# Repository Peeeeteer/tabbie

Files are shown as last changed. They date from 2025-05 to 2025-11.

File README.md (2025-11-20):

<div align="center">

# 🤖 Tabbie  
Ever wanted a **to-do app with a Cute Face**? One that lives on your desk?

**That's Tabbie.**

[🛠️ Get started](https://tabbie.me) · [📺 Follow the build](https://www.youtube.com/@LloydDecember1) · [👥 Join the community](https://www.reddit.com/r/deskbuddy/) · [📘 Hardware Starer Guide](https://tabbie.me/hardware-guide)

</div>

---

## 🧠 What is Tabbie?

**Tabbie is a DIY desk robot that helps you work, focus, and learn.**  
It's like a to-do app — but physical, local, and full of personality.

Tabbie lives on your desk, connects to your computer, and helps with small daily things like:
- ✅ Managing your to-do list
- ⏲️ Running Pomodoro timers
- 🔔 Setting reminders (like "drink water every 30 mins")
- 😋 Making faces, moving around, and being silly
- 🗣️ Talking to you (coming soon!)

**Think:** a mini Twitch streamer sitting on your desk, cheering you on — but also keeping you on track.

https://github.com/user-attachments/assets/2cbf9e57-a491-4764-b69d-660fd9c50714

## ✨ Made to Be Built

Tabbie is open-source and totally customizable.  
You can build it yourself with 3D-printed parts and off-the-shelf components — [or just buy a Kit.](https://www.tabbie.me/buy)

Powered by:
- An ESP32 microcontroller
- A local React dashboard that talks to the robot
- 3D-printed body with custom designs and colors

If you're new to electronics:  
I also put together a [simple hardware starter guide](https://tabbie.me/hardware-guide) that explains the basics behind Tabbie

---

## 🚀 Get Started(STIL WIP, BUT FULL INSTRUCTIONS COMING NOVEMBER 10)

Start with the step-by-step guide (WITH A **15 MINUTE VIDEO TUTORIAL**):
- 👉 See: [`docs/get_started.md`](docs/get_started.md)

That guide covers:
- Installing the Dashboard
- Flashing the ESP32 firmware
- Connecting the dashboard to your Tabbie
- First run checklist

<!-- 
**📚 Dont know anything about electronics?**  
Go here and get started → [`docs/learning/README.md`](docs/learning/README.md) — This is my mini-roadmap that I did... try learning the same _(not sure if its the best and Im kinda stupid but yea)_
-->
---

## 🗂️ Project Structure

```txt
tabbie/
├── app/                      # React control panel
│
├── firmware/                 # Code that runs on devices
│
├── hardware/                 # Physical build assets (STL files)
│
├── docs/                     # Docs (kept simple for now)
│   ├── get_started.md
│
├── CONTRIBUTING.md
└── README.md
```

---

Want to understand Tabbie’s internals or eventually modify the hardware? [There’s a beginner-friendly hardware guide here](https://tabbie.me/hardware-guide)

## 🤝 Contributing

Contributions are welcome, but lets talk first!

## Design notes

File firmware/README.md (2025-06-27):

I purchased this small one (These are affiliate links. I may earn a commission at no extra cost to you)

EU: 22 EUR
https://amzn.to/4jXdnxq

## 1. ESP32 working test

For the setup I again did this:
https://gyazo.com/37ea603742f484d6cf2d05bb1ba84736

Simple check for if the onboard led is blinking aka that everything is working fine.

## 2. ESP32 + GME12864-11

We can get started with the ESP32 + GME12864-11 LED screen, basicly the one I got here https://amzn.to/4jXdnxq
Idea is to just show a face
Maybe then show a animation & then we could test the other screens I think?

The code is as it is under the ## 2. ESP32 + GME12864-11

And now you just need to connect to the esp32:

VCC → 3.3V 
GND → GND
SCL → GPIO 22 (default I2C clock pin)
SDA → GPIO 21 (default I2C data pin)

Now are display a simple static thing on the screen:
Image of the thing on my phone, will link later.

I quized myself as usual to understand the code but yea.

# 3. ESP32 + GME12864-11 + lopaka.app

Now using:
https://lopaka.app/gallery#trending

We will create a looping animation of the character blinking and the looking to the side.

Yea, 
just go to the url and make your 4 face screens & or just copy the ones I have and see the code.

### Just thinking

Seems like after more consideration, I will be switching to a Raspberry Pi Zero 2 W

the esp32 is not a good usecase in our situation, as esp32 is more of a outdoor low battery consumtion thing rather than mine on pc, gets to be charger all the time thing.

So basicly esp32 is just for the exact small electronic things, like quick weather sensor that sends data to your server and such

Simple "do one thing well" devices

Not sure, that might be version 2 and for now ill just make aversion 1 that does all the calculation etc.. on the pc/localy and just sends what to do the esp32.

Like,
User just started pomodoro (focus face or something?)

Exported chat to D:\tabbie 

# 4. ESP32 + GME12864-11 + lopaka.app + send faces

The goal now is to see whether for battery safety and not using rasberypie to use esp32 as just sort of middle maschine as I dont want to use rasberypie and some weird large batteries to Tabbie.

All the calculation and things will happen on the local pc/laptop, as in if we start a pomodoro, we send the animations for that to the esp32 and wipe the rest

So lets just actually try that, a simple "waiting animation" that is always on the esp32 and once we click on "Start pomodoro" in the dashboard, we show the "focus face"

Also,
We need resue the .env file and the load_env.py file from the previous esp32 basics.

So yes,
We are able to stream images / bits over wifi to show on the face but actually maybe not required.

anyway,
added the same thing now where users are able ot control over wifi and also in the frontend dashboard add their wifi login and such.

A real pain in the ass to make it as easy as possible for someone to connect their tabbie and ran into a bunch of bugs when setting the thing up with a new esp32 which is good to learn now 
not once people start using it.

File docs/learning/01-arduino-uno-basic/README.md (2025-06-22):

I purchased these things (These are affiliate links. I may earn a commission at no extra cost to you)

EU: 20 EUR
https://amzn.to/4jXdnxq
https://amzn.to/3GIhij3

US: $25
https://amzn.to/42Nb3lt
https://amzn.to/3RBpxQt

And the goal was to:
Show a screen and a mic and have it read and show that thing it read on a web page?

## Things I did.

## 1.1 Lights
I installed vs code ardunio extensions

1.2.
Watched this tutorial:
https://www.youtube.com/watch?v=I0ZIrzoI61g

1.3.
Ran into some problems running Arduino with VSCODE, watching this
https://www.youtube.com/watch?v=gQ2lsSuXvVU

Ended up installing platformio.ini which seems to be the main one anyone uses for boards like these?

If your on a Mac and you dont see the extension, you will need to pip install the platformio and then manually do the project init and such, without the extension gui (But if you on VS code it should be fine)

NOW Arudino does the ligth thing:

The code is inside ../src/main.cpp 
Dont forget to pio lib install "Servo" (Komment and unkomment code for each part)

https://github.com/user-attachments/assets/9d56f506-6bd0-425b-b68e-76e2e1bc5504

On to next thing.

## 2.1 Potentiometer

With a Potentiometer, you can now turn the ligth led up and down. Same code in the main.cpp file 

https://github.com/user-attachments/assets/5a38a1b8-3e5c-4d68-8e2c-4ae03be7157e

2.2 Potentiometer

Exact Same code but you can also use it to turn a Fan Motor... which is cool.

https://github.com/user-attachments/assets/15904203-2893-4038-a614-c387fcf38571

## 3.0 Servos/Step Motors 

Move servo with ptanetiomoter.

## 3.1 Same thing, but now with tabbie head (The head will definetly look better in the future)

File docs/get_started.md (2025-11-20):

# Getting Started with Tabbie

> STILL WORKING ON THIS - COME BACK ON NOVEMBER 10, 2025 (_but you can alrdy grab the parts on amazon now if you want save time)_

A mini Twitch streamer on your desk, cheering you on, but also keeping you focused. Lets make one

---

## What You'll Need

### The Parts (~$18 USD / ~€16 EUR total)
- **ESP32** (the robot's brain)
- **1.3" OLED Screen** (the face)
- **3D Printed Parts** (the body)
- **Jumper Wires** (connecting everything)

I recommend buying the parts on **Amazon or Aliexpress**  
**Amazon** is safe choice and fast shipping, but will be more expensive  
**Aliexpress** is cheaper, but things sometimes arrive broken and shipping takes long  

**Amazon EU:**
- [ESP32 USB-C](https://amzn.to/4mDWJ6Z) (~14 EUR) 
- [OLED Screen - Pack of 3](https://amzn.to/4nxXHCO) (~18.99 EUR)
- [JumperWires -  Full pack](https://amzn.to/4mOGZ0I) (~6.40 EUR)
- [PLA Filament for 3D printing](https://amzn.to/46QfHkC) (~14 EUR)

**Amazon US**
- [ESP32 USB-C](https://amzn.to/4mGymW4) (~13.99 USD)
- [OLED Screen](https://amzn.to/4nGTbSQ) (~17.99 USD)
- [JumperWires -  Full pack](https://amzn.to/4nFxh2a) (~6.80 USD)
- [PLA Filament for 3D printing](https://amzn.to/46yAlqL) (~13.99 USD)

**Aliexpress Worldwide:**
- [ESP32 USB-C](https://s.click.aliexpress.com/e/_c3wydxSb) (~6.99 USD / 5.20 EUR a piece)
- [1.3 INCH OLED Screen white](https://s.click.aliexpress.com/e/_c30oI6Nd) (~5.35 USD / 4.50 EUR)
- [JumperWires](https://s.click.aliexpress.com/e/_c3SbwD0R) (~3.30 USD / 2.59 EUR)
- [PLA Filament for 3D printing](https://s.click.aliexpress.com/e/_c3O5ECAR) (~15.50 USD / 13.50 EUR)

*These are affiliate links - I get 3% at no extra cost to you!*

## **Don't want to deal with parts & printing?** [Pre-order a complete kit here](https://www.tabbie.me/buy/kit)

<div align="center">

### **START. How to Build Tabbie**
**The video below covers everything for both Windows and Mac users.**

</div>

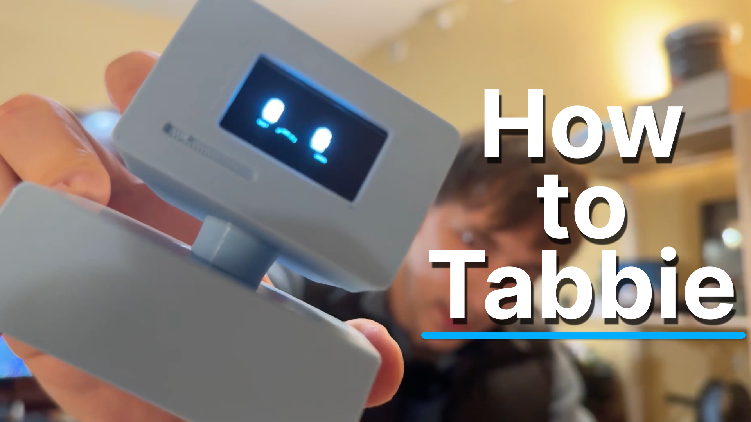
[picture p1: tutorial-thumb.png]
Watch the video (https://youtu.be/OyjsMKxYkQ0)


---

### STEP 1: Install & Download 

>Install:
1. **Node.js** (v18 or newer) - [Download](https://nodejs.org/) - Runs the dashboard web app
2. **Visual Studio Code** - [Download](https://code.visualstudio.com/) - Editor to view and modify code
3. **PlatformIO** (for programming the ESP32) - [Download](https://platformio.org/) - Uploads firmware to ESP32
4. **Git** - [Download Git](https://git-scm.com/)  To download via command line using `git clone`  

>Download:

**Option A: Using Git**   

```bash
git clone https://github.com/Peeeeteer/tabbie.git
cd tabbie
```

**Option B: Download as ZIP**

- Go to https://github.com/Peeeeteer/tabbie
- Click the green “Code” button
- Select “Download ZIP”
- Extract it somewhere easy to find

*[Image here showing how to download ZIP]*

### STEP 2: Print the Body/Enclosure   

1. Use the STL files from the `/hardware` folder & print
      - `hardware/GCODE.bgcode`
      - `hardware/STL/antenna.stl`
      - `hardware/STL/antenna2.stl`
      - `hardware/STL/bottom_case.stl`
      - `hardware/STL/case.stl`
      - `hardware/STL/neck.stl`
      - `hardware/STL/panel.stl`
      - `hardware/STL/top_case.stl`

**Tip:** Turn on supports for `neck.stl` and `top_case.stl` 

### STEP 3: Install ESP32 Drivers

Your ESP32 (brains) needs special drivers to talk to your computer.

**Windows Users:**
1. Download drivers from [Silicon Labs](https://www.silabs.com/software-and-tools/usb-to-uart-bridge-vcp-drivers?tab=downloads)
2. Install them
3. Plug in your ESP32 with a USB cable
4. Open Device Manager - you should see "Silicon Labs CP210x USB to UART Bridge"

**Mac/Linux Users:**
- Usually works automatically when you plug it in
- If it doesn't work, type this in Terminal: `brew install --cask silicon-labs-vcp-driver`

---

### STEP 4: Connect the Parts

**Wiring Guide:**
1. Partly Asemble Enclosure (as per video)
2. Connect the OLED screen to ESP32:
   - SDA wire → GPIO 21 (D21)
   - SCK/SCL wire → GPIO 22 (D22)
   - VDD → 3.3V 
   - GND → GND (Ground)

Keep it partly assembled (we need to upload code and make sure everything works first)

GG. done

---

### STEP 5: Program Your ESP32

1. **Navigate to the firmware folder:**

```bash
cd firmware
```

2. **Set up your WiFi credentials:**
   - Find the file `src/.env.example`
   - Make a copy of it in the same location
   - Rename the copy to `.env` (remove "example")
   - Open `.env` in Visual Studio Code or any text editor
   - Add your WiFi details: 

```
WIFI_SSID=your_wifi_name_here
WIFI_PASSWORD=your_wifi_password_here
```

**Tip:** Make sure its the same Wifi that your computer is connected to 

3. **Upload the code to your ESP32:**

```bash

# Go to the dashboard folder
cd firmware

pio run --target upload
```

**Tip:** If upload fails, hold down the BOOT button on your ESP32 while uploading
and make sure that your are in still in the `firmware` directory when uploading 

4. Finish assembling Tabbie.

Put the screen in the front -> front in the head

---

### STEP 6: Set Up the React Dashboard

Open your terminal/command and run:

```bash
# Go to the dashboard folder
cd app

# Install everything it needs
npm install

# Start it up
npm run dev
```

The dashboard will open at `http://localhost:8080` in your web browser.

---

### STEP 7: Connect Everything Together

1. **Open the dashboard** at `http://localhost:8080` in your browser
2. Follow the onboarding steps
3. **Watch the magic!** Tabbie should start showing its idle animation

**Tip:** Sometimes things just break, so disconnect tabbie for a few seconds and plug back in if wifi is not connecting properly. 

---

### Let's Use Tabbie!

**Create Tasks**
- Go to the Tasks tab
- Add things you need to do
- Start pomodors for tasks
- Tick it of when finished

Tabbie will show focus, happy,relax and bored animations a long the way to keep you focused.

**Important:**  
All your tasks/notes etc... are only saved on your computer, no one can access them.

---

## Troubleshooting

### ESP32 Won't Connect
- Double-check your WiFi name and password in the `.env` file and press "save"
- Make sure your ESP32 and computer are on the same WiFi network

### Dashboard Won't Start
- Make sure you ran `npm install` in the `dashboard` folder
- Check that you have Node.js v18 or newer (type `node --version` to check)
- Try running `npm run dev` again from the `dashboard` folder

### Can't Upload Code to ESP32
- Install the CP2102 drivers (see Step 3)
- Hold the BOOT button on ESP32 while uploading
- Check your USB cable (some cables only charge, they don't transfer data)

**Need more help?** Join the community:
- [Discord](https://discord.gg/7er2Ysjc) - [Reddit](https://www.reddit.com/r/deskbuddy/) - [YouTube](https://www.youtube.com/@LloydDecember1) - [GitHub](https://github.com/Peeeeteer/tabbie) - [X](https://x.com/llo7d)

---

## That's It!

If this helped you, consider giving the project a star on [GitHub](https://github.com/Peeeeteer/tabbie)!

Happy building!

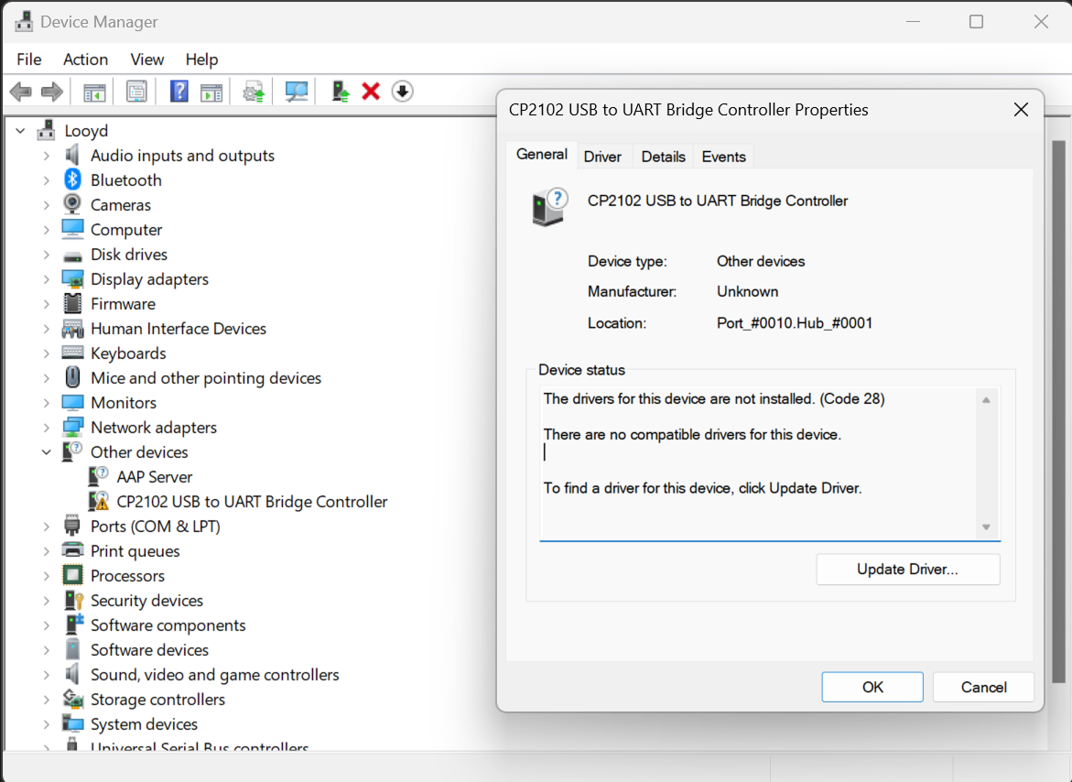
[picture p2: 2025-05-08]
docs/learning/02-esp-32-basics/media/esp32-1.png

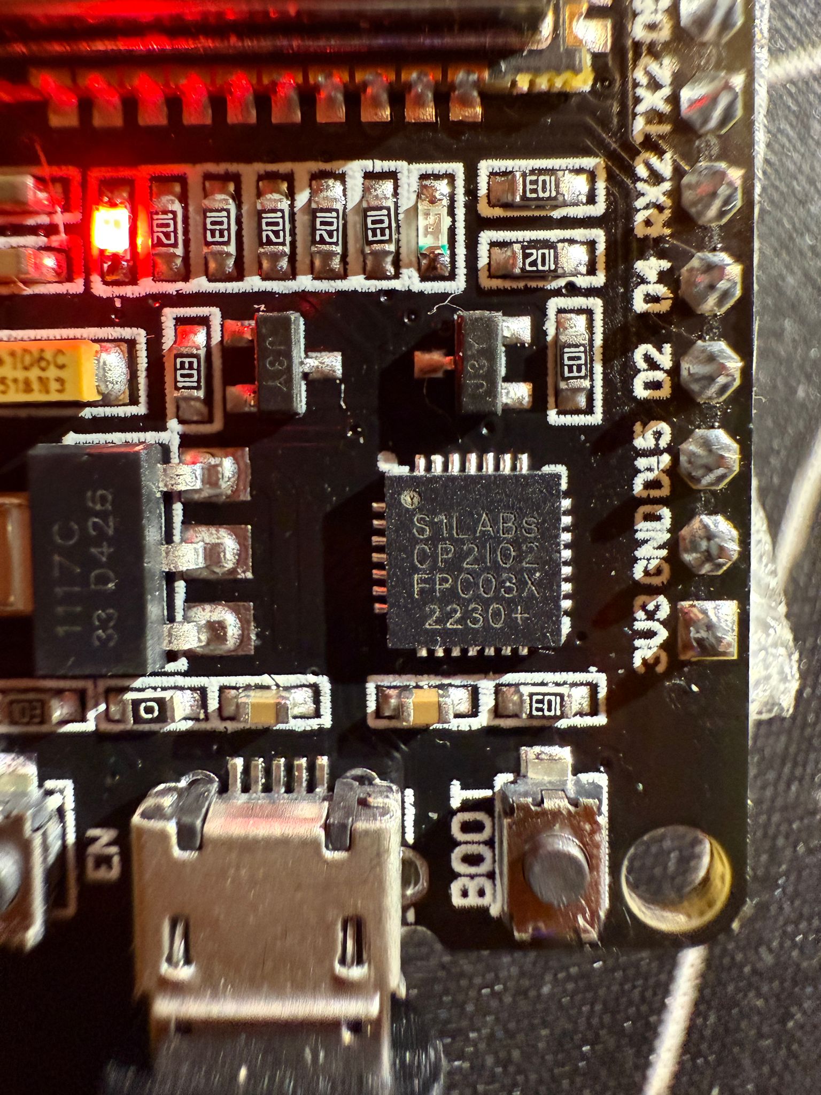
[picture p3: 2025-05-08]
docs/learning/02-esp-32-basics/media/esp32-2.jpeg

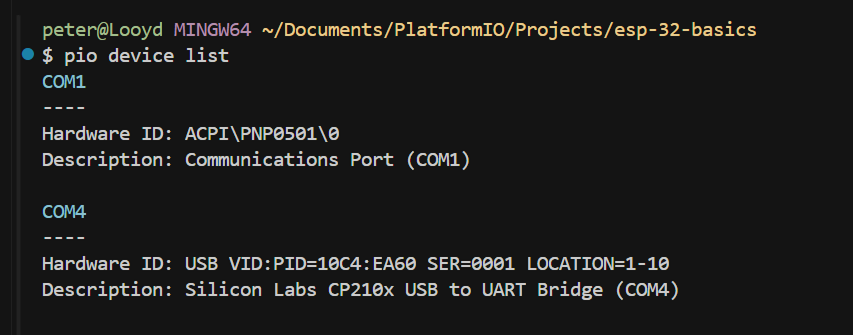
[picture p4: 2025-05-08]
docs/learning/02-esp-32-basics/media/esp32-3.png

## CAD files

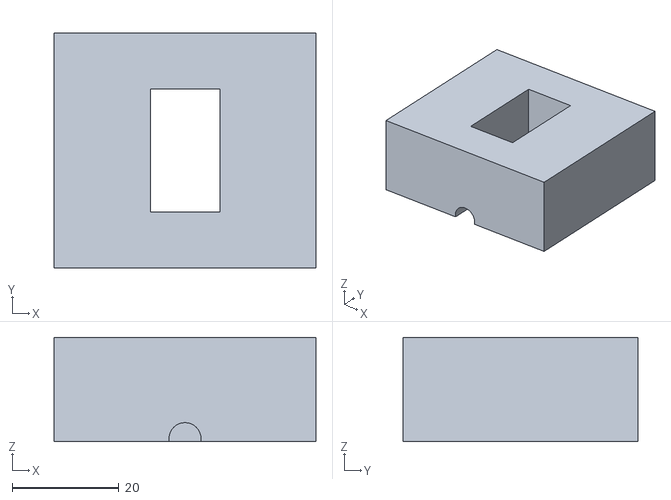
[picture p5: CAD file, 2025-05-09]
docs/learning/01-arduino-uno-basic/3d-files/tabbie-neck.stl
49.0 x 44.0 x 19.5

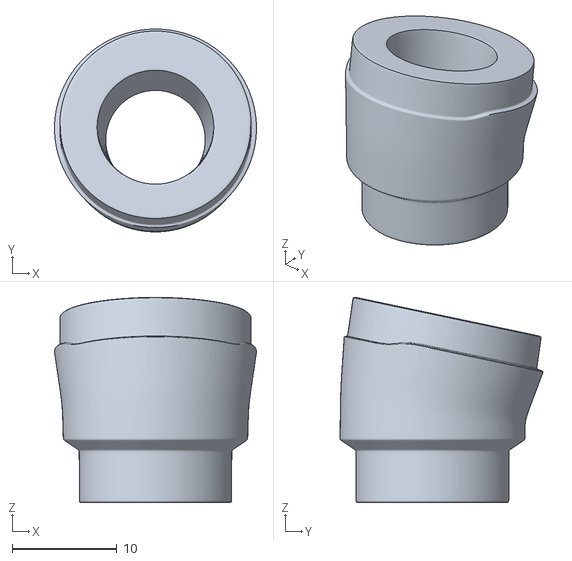
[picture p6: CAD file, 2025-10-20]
hardware/STL/neck.stl
19.3 x 19.3 x 19.6

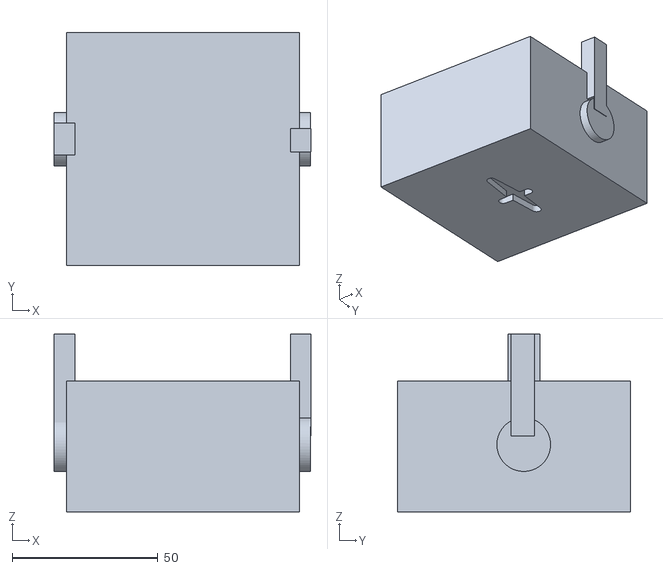
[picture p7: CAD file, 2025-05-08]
docs/learning/01-arduino-uno-basic/3d-files/tabbie-head.stl
88.2 x 80.0 x 61.0

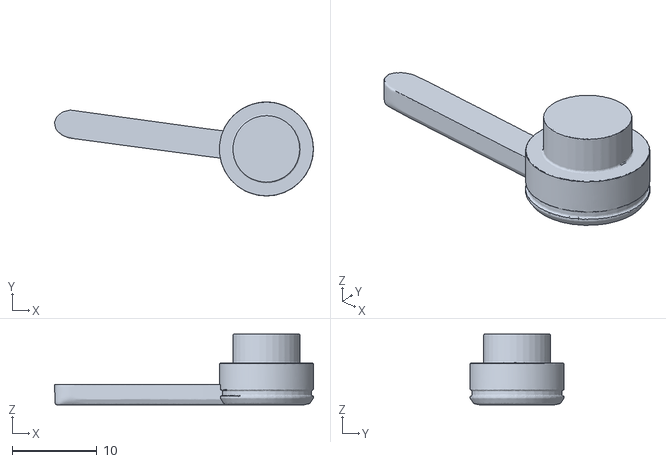
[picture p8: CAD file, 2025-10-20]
hardware/STL/antenna2.stl
30.6 x 11.1 x 8.37

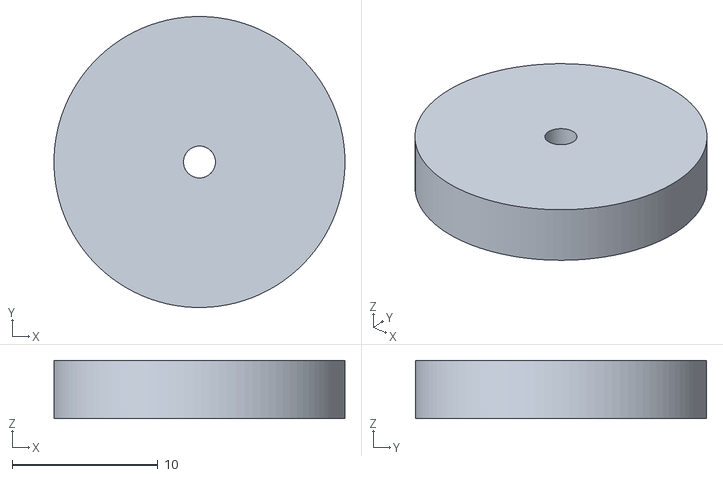
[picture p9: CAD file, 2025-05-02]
docs/learning/01-arduino-uno-basic/3d-files/circle 2 cm with hole 0.22 cm.stl
20.0 x 20.0 x 4.00

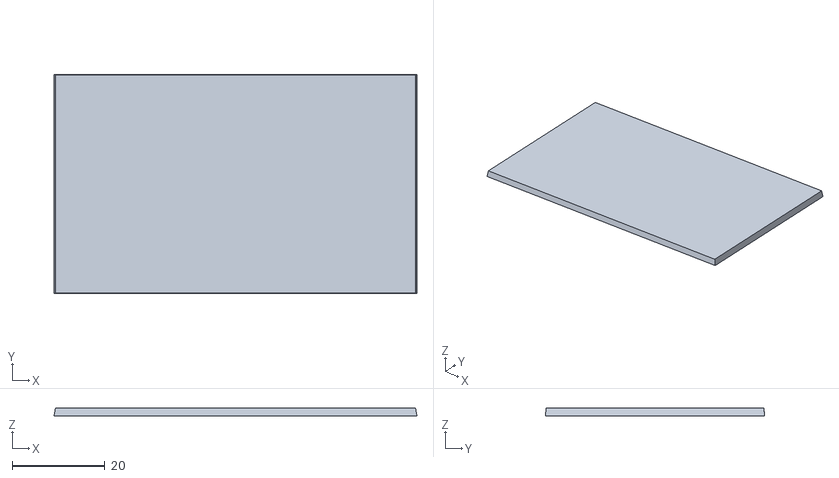
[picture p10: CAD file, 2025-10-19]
hardware/STL/bottom_case.stl
78.1 x 47.2 x 1.76

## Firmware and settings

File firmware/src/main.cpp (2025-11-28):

#include <Wire.h>
#include <WiFi.h>
#include <WebServer.h>
#include <ArduinoJson.h>
#include <U8g2lib.h>
#include <Preferences.h>
#include <ESPmDNS.h>
#include <DNSServer.h>

// Animation data
#include "idle01.h"
#include "focus01.h"
#include "relax01.h"
#include "love01.h"
#include "startup01.h"
#include "angry_bitmap.h"  // Keep angry as static image

// OLED display configuration - Using U8g2 with SH1106 driver
U8G2_SH1106_128X64_NONAME_F_HW_I2C display(U8G2_R0, /* reset=*/ U8X8_PIN_NONE);

// Web server on port 80
WebServer server(80);

// DNS server for captive portal
DNSServer dnsServer;

// WiFi credentials storage
Preferences preferences;

// Current state
String currentAnimation = "startup";
String currentTask = "";
unsigned long animationStartTime = 0;
unsigned long startupTime = 0;
bool hasCompletedStartup = false;
bool isInSetupMode = false;
String wifiStatus = "disconnected";
String lastError = "";

// WiFi connection state machine
String savedSSID = "";
String savedPassword = "";
unsigned long wifiConnectStartTime = 0;
bool wifiInitialized = false;
bool wifiConnecting = false;
bool webServerStarted = false;

const int MAX_WIFI_ATTEMPTS = 3;
int wifiAttemptCount = 0;
unsigned long wifiRetryWaitUntil = 0;

// Debug mode - shows device info on OLED when triggered
bool isDebugMode = false;
unsigned long debugModeStartTime = 0;
const unsigned long DEBUG_MODE_DURATION = 8000; // Show debug info for 8 seconds

// Physical button for showing debug info
// Using GPIO27 - safe pin that's not a strapping pin
const int DEBUG_BUTTON_PIN = 27;
unsigned long lastButtonPress = 0;
const unsigned long BUTTON_DEBOUNCE_MS = 300; // Debounce time

// Setup mode configuration
const char* SETUP_SSID = "Tabbie-Setup";
const char* MDNS_NAME = "tabbie";

// Function declarations
void setupDisplay();
void loadWiFiCredentials();
void handleWiFiConnection();
void startSetupMode();
void startNormalMode();
void setupWebServer();
void setupMDNS();
void handleRoot();
void handleSetupPage();
void handleWiFiConfig();
void handleStatus();
void handleAnimation();
void handleWiFiSettings();
void handleCORS();
void updateDisplay();
void drawSetupMode();
void drawConnecting();
void drawConnected();
void drawError();
void drawIdleAnimation();
void drawFocusAnimation();
void drawRelaxAnimation();
void drawLoveAnimation();
void drawStartupAnimation();
void drawAngryImage();
void drawPomodoroAnimation();
void drawTaskCompleteAnimation();
void drawDebugInfo();
void handleDebug();
void handleReset();
void checkDebugButton();
void prepareWiFiForRetry(unsigned long delayMs = 0);
void onWiFiConnectionFailure(const String& reason);

void setup() {
  Serial.begin(115200);
  Serial.println("🤖 Tabbie Assistant Starting...");
  
  // Record startup time
  startupTime = millis();
  
  // Setup debug button (GPIO0 = BOOT button on most ESP32 boards)
  pinMode(DEBUG_BUTTON_PIN, INPUT_PULLUP);
  
  // CRITICAL: Clean WiFi state from any previous boot/mode
  // This prevents issues when switching between AP and STA modes
  WiFi.persistent(false);  // Don't save WiFi config to flash
  WiFi.disconnect(true);   // Disconnect and clear saved credentials
  WiFi.mode(WIFI_OFF);     // Turn off WiFi completely
  delay(200);              // Give hardware time to reset
  wifiAttemptCount = 0;
  wifiRetryWaitUntil = 0;
  
  // Initialize components
  setupDisplay();
  
  // Initialize preferences
  preferences.begin("tabbie", false);
  
  // Load WiFi credentials (don't connect yet - animations first!)
  loadWiFiCredentials();
  
  // DON'T setup web server here - it will be started in startNormalMode() or startSetupMode()
  // after WiFi is properly initialized
  
  Serial.println("✅ Tabbie initialized - animations will play while WiFi connects");
}

void setupDisplay() {
  Wire.begin(21, 22);
  
  display.begin();
  display.clearBuffer();
  // Don't show "Starting..." text - just clear the display
  // Startup animation will begin immediately in loop()
  display.sendBuffer();
  
  Serial.println("✅ OLED Display initialized (U8g2 SH1106)");
}

void loadWiFiCredentials() {
  Serial.println("📡 Loading WiFi credentials...");
  
  // Check saved preferences (from captive portal setup)
  savedSSID = preferences.getString("wifi_ssid", "");
  savedPassword = preferences.getString("wifi_password", "");
  
  if (savedSSID.length() > 0 && savedPassword.length() > 0) {
    Serial.print("📡 Found saved credentials for: ");
    Serial.println(savedSSID);
    wifiStatus = "connecting";
    wifiAttemptCount = 0;
    wifiRetryWaitUntil = 0;
  } else {
    Serial.println("🔧 No credentials - entering setup mode");
    startSetupMode();
  }
}

void prepareWiFiForRetry(unsigned long delayMs) {
  WiFi.disconnect(true);
  WiFi.mode(WIFI_OFF);
  delay(100);

  wifiInitialized = false;
  wifiConnecting = false;
  wifiConnectStartTime = 0;
  wifiRetryWaitUntil = delayMs > 0 ? millis() + delayMs : 0;
  
  // Reset web server flag so it restarts on new network
  webServerStarted = false;
}

void onWiFiConnectionFailure(const String& reason) {
  wifiConnecting = false;
  wifiInitialized = false;
  wifiConnectStartTime = 0;

  Serial.print("❌ WiFi connection failed: ");
  Serial.println(reason);

  if (wifiAttemptCount < MAX_WIFI_ATTEMPTS) {
    Serial.print("🔁 Retrying WiFi (");
    Serial.print(wifiAttemptCount);
    Serial.print("/");
    Serial.print(MAX_WIFI_ATTEMPTS);
    Serial.println(")...");
    prepareWiFiForRetry(1000);
    wifiStatus = "connecting";
    return;
  }

  Serial.println("🚫 WiFi retries exhausted. Entering setup mode.");
  wifiStatus = "failed";
  lastError = reason + " - " + savedSSID;
  wifiRetryWaitUntil = 0;
  wifiAttemptCount = 0;
  startSetupMode();
}

void handleWiFiConnection() {
  // Don't handle WiFi if in setup mode
  if (isInSetupMode) {
    return;
  }
  
  // Respect backoff window between retries
  if (!wifiInitialized && wifiStatus == "connecting" && wifiRetryWaitUntil != 0) {
    if ((long)(wifiRetryWaitUntil - millis()) > 0) {
      return;
    }
    wifiRetryWaitUntil = 0;
  }

  // Initialize WiFi when we're ready for a new attempt
  if (!wifiInitialized && wifiStatus == "connecting") {
    wifiAttemptCount++;

    Serial.print("📡 Starting WiFi connection to: ");
    Serial.print(savedSSID);
    Serial.print(" (attempt ");
    Serial.print(wifiAttemptCount);
    Serial.print("/");
    Serial.print(MAX_WIFI_ATTEMPTS);
    Serial.println(")");

    WiFi.mode(WIFI_STA);
    WiFi.setAutoReconnect(true);
#ifdef ARDUINO_ARCH_ESP32
    WiFi.setAutoConnect(true);
#endif
    WiFi.begin(savedSSID.c_str(), savedPassword.c_str());

    wifiInitialized = true;
    wifiConnecting = true;
    wifiConnectStartTime = millis();
    Serial.println("📡 WiFi initialized, connecting...");
    return;
  }

  // Check connection progress
  if (wifiConnecting) {
    wl_status_t status = WiFi.status();

    if (status == WL_CONNECTED) {
      Serial.print("✅ WiFi connected! IP: ");
      Serial.println(WiFi.localIP());
      wifiStatus = "connected";
      wifiConnecting = false;
      wifiInitialized = true;
      wifiRetryWaitUntil = 0;
      wifiAttemptCount = 0;
      startNormalMode();
      return;
    }

    if (status == WL_CONNECT_FAILED) {
      onWiFiConnectionFailure("CONNECT_FAILED");
      return;
    }

    if (status == WL_NO_SSID_AVAIL) {
      onWiFiConnectionFailure("NO_SSID");
      return;
    }

    if (status == WL_DISCONNECTED && (millis() - wifiConnectStartTime) > 7000) {
      onWiFiConnectionFailure("DISCONNECTED");
      return;
    }

    if (millis() - wifiConnectStartTime > 15000) {
      onWiFiConnectionFailure("Timeout");
      return;
    }
  }

  // Handle unexpected disconnections once connected
  if (wifiStatus == "connected" && WiFi.status() != WL_CONNECTED) {
    static unsigned long lastReconnect = 0;
    if (millis() - lastReconnect > 30000) {
      Serial.println("📡 Reconnecting...");
      wifiStatus = "connecting";
      wifiInitialized = false;
      wifiConnecting = false;
      wifiAttemptCount = 0;
      prepareWiFiForRetry(500);
      lastReconnect = millis();
    }
  }
}

void startSetupMode() {
  Serial.println("🔍 DEBUG: Starting startSetupMode()");
  isInSetupMode = true;
  wifiStatus = "setup";
  wifiAttemptCount = 0;
  wifiRetryWaitUntil = 0;
  
  Serial.println("🔧 Starting setup mode...");
  
  // Properly clean up any STA mode state before starting AP
  WiFi.disconnect(true);
  WiFi.mode(WIFI_OFF);
  delay(100);
  
  // Start in AP mode for setup
  WiFi.mode(WIFI_AP);
  Serial.println("🔍 DEBUG: WiFi mode set to AP");
  
  bool apResult = WiFi.softAP(SETUP_SSID);
  Serial.print("🔍 DEBUG: WiFi.softAP() result: ");
  Serial.println(apResult ? "success" : "failed");
  
  // Start DNS server for captive portal
  dnsServer.start(53, "*", WiFi.softAPIP());
  Serial.println("🔍 DEBUG: DNS server started");
  
  // Setup web server now that WiFi is initialized
  setupWebServer();
  
  Serial.print("📶 Setup WiFi started - SSID: ");
  Serial.println(SETUP_SSID);
  Serial.print("🌐 Setup IP: ");
  Serial.println(WiFi.softAPIP());
  
  updateDisplay();
  Serial.println("🔍 DEBUG: startSetupMode() completed");
}

void startNormalMode() {
  Serial.println("🔍 DEBUG: Starting startNormalMode()");
  isInSetupMode = false;
  wifiStatus = "connected";
  wifiAttemptCount = 0;
  wifiRetryWaitUntil = 0;
  
  Serial.print("🔍 DEBUG: WiFi status in normal mode: ");
  Serial.println(WiFi.status());
  Serial.print("🔍 DEBUG: IP address: ");
  Serial.println(WiFi.localIP());
  
  // Setup web server now that WiFi is initialized
  setupWebServer();
  
  // Setup mDNS
  setupMDNS();
  
  Serial.println("✅ Normal mode started");
  updateDisplay();
  Serial.println("🔍 DEBUG: startNormalMode() completed");
}

void setupMDNS() {
  if (MDNS.begin(MDNS_NAME)) {
    MDNS.addService("http", "tcp", 80);
    Serial.print("✅ mDNS started: ");
    Serial.print(MDNS_NAME);
    Serial.println(".local");
  } else {
    Serial.println("❌ mDNS setup failed");
  }
}

void setupWebServer() {
  // Only setup once
  if (webServerStarted) {
    return;
  }
  
  // Handle captive portal redirect
  server.onNotFound([]() {
    if (isInSetupMode && server.method() == HTTP_GET) {
      handleSetupPage();
    } else if (server.method() == HTTP_OPTIONS) {
      handleCORS();
    } else {
      server.send(404, "text/plain", "Not found");
    }
  });
  
  // Setup mode endpoints
  server.on("/", HTTP_GET, []() {
    if (isInSetupMode) {
      handleSetupPage();
    } else {
      handleRoot();
    }
  });
  server.on("/setup", HTTP_GET, handleSetupPage);
  server.on("/configure", HTTP_POST, handleWiFiConfig);
  
  // Normal mode endpoints
  server.on("/api/status", HTTP_GET, handleStatus);
  server.on("/api/status", HTTP_OPTIONS, handleCORS);
  server.on("/api/animation", HTTP_POST, handleAnimation);
  server.on("/api/animation", HTTP_OPTIONS, handleCORS);
  server.on("/api/debug", HTTP_POST, handleDebug);
  server.on("/api/debug", HTTP_OPTIONS, handleCORS);
  server.on("/api/reset", HTTP_POST, handleReset);
  server.on("/api/reset", HTTP_OPTIONS, handleCORS);
  server.on("/wifi", HTTP_GET, handleWiFiSettings);
  server.on("/wifi", HTTP_POST, handleWiFiConfig);
  
  server.begin();
  webServerStarted = true;
  Serial.println("✅ Web server started");
}

void loop() {
  // Check if debug button is pressed
  checkDebugButton();
  
  // Handle DNS server in setup mode
  if (isInSetupMode) {
    dnsServer.processNextRequest();
  }
  
  // Handle WiFi connection (non-blocking, runs in background)
  handleWiFiConnection();
  
  // Handle web server requests
  server.handleClient();
  
  // Update display animation (always runs, never blocked!)
  updateDisplay();
  
  delay(5);
}

void handleCORS() {
  server.sendHeader("Access-Control-Allow-Origin", "*");
  server.sendHeader("Access-Control-Allow-Methods", "GET, POST, OPTIONS");
  server.sendHeader("Access-Control-Allow-Headers", "Content-Type");
  server.send(200, "text/plain", "");
}

void handleRoot() {
  server.sendHeader("Access-Control-Allow-Origin", "*");
  String html = "<!DOCTYPE html><html><head><title>Tabbie Assistant</title>";
  html += "<style>body{font-family:Arial,sans-serif;max-width:600px;margin:50px auto;padding:20px;}";
  html += ".status{background:#e8f5e8;padding:15px;border-radius:8px;margin:20px 0;}";
  html += ".button{background:#007bff;color:white;padding:10px 20px;border:none;border-radius:5px;margin:5px;cursor:pointer;}";
  html += ".button:hover{background:#0056b3;}</style></head><body>";
  html += "<h1>Tabbie Assistant</h1>";
  html += "<div class='status'><h3>Status: Connected!</h3>";
  html += "<p>Current Animation: <span id='current-animation'>Loading...</span></p>";
  html += "<p>WiFi: " + WiFi.SSID() + "</p>";
  html += "<p>IP: " + WiFi.localIP().toString() + "</p></div>";
  html += "<h3>Test Animations:</h3>";
  html += "<button class='button' onclick=\"sendAnimation('idle')\">Idle</button>";
  html += "<button class='button' onclick=\"sendAnimation('pomodoro','Focus Session')\">Pomodoro</button>";
  html += "<button class='button' onclick=\"sendAnimation('complete','Task Done!')\">Complete</button>";
  html += "<h3>Settings:</h3>";
  html += "<button class='button' onclick=\"window.location='/wifi'\">WiFi Settings</button>";
  html += "<button class='button' style='background:#dc3545;' onclick=\"resetWiFi()\">Reset WiFi</button>";
  html += "<script>";
  html += "async function resetWiFi(){if(confirm('This will clear WiFi settings and restart Tabbie. Continue?')){try{await fetch('/api/reset',{method:'POST'});alert('Tabbie is restarting in setup mode...');}catch(e){alert('Tabbie is restarting...');}}}";
  html += "async function sendAnimation(type,task=''){";
  html += "try{const response=await fetch('/api/animation',{method:'POST',headers:{'Content-Type':'application/json'},body:JSON.stringify({animation:type,task:task})});";
  html += "if(response.ok){updateStatus();}}catch(e){console.error('Failed to send animation:',e);}}";
  html += "async function updateStatus(){try{const response=await fetch('/api/status');const data=await response.json();";
  html += "document.getElementById('current-animation').textContent=data.animation;}catch(e){console.error('Failed to get status:',e);}}";
  html += "setInterval(updateStatus,2000);updateStatus();";
  html += "</script></body></html>";
  
  server.send(200, "text/html", html);
}

void handleSetupPage() {
  String html = "<!DOCTYPE html><html><head><title>Tabbie Setup</title>";
  html += "<meta name='viewport' content='width=device-width,initial-scale=1'>";
  html += "<style>body{font-family:Arial,sans-serif;max-width:400px;margin:50px auto;padding:20px;background:#f5f5f5;}";
  html += ".container{background:white;padding:30px;border-radius:10px;box-shadow:0 2px 10px rgba(0,0,0,0.1);}";
  html += "h1{text-align:center;color:#333;margin-bottom:30px;}";
  html += "input,select{width:100%;padding:12px;margin:10px 0;border:1px solid #ddd;border-radius:5px;font-size:16px;}";
  html += "button{width:100%;background:#007bff;color:white;padding:15px;border:none;border-radius:5px;font-size:16px;cursor:pointer;}";
  html += "button:hover{background:#0056b3;}";
  html += ".error{color:#dc3545;margin:10px 0;padding:10px;background:#f8d7da;border-radius:5px;}";
  html += "</style></head><body><div class='container'>";
  html += "<h1>Tabbie Setup</h1>";
  
  if (lastError.length() > 0) {
    html += "<div class='error'>Error: " + lastError + "</div>";
  }
  
  html += "<form action='/configure' method='POST'>";
  html += "<label>WiFi Network:</label>";
  html += "<select name='ssid' required>";
  
  // Scan for networks
  int networks = WiFi.scanNetworks();
  for (int i = 0; i < networks; i++) {
    html += "<option value='" + WiFi.SSID(i) + "'>" + WiFi.SSID(i) + "</option>";
  }
  
  html += "</select>";
  html += "<label>Password:</label>";
  html += "<input type='password' name='password' placeholder='WiFi Password' required>";
  html += "<button type='submit'>Connect Tabbie</button>";
  html += "</form>";
  html += "<p style='text-align:center;margin-top:20px;font-size:12px;color:#666;'>";
  html += "Tabbie will connect to your WiFi and restart.</p>";
  html += "</div></body></html>";
  
  server.send(200, "text/html", html);
}

void handleWiFiConfig() {
  String ssid = server.arg("ssid");
  String password = server.arg("password");
  
  if (ssid.length() == 0) {
    lastError = "No WiFi network selected";
    handleSetupPage(); // Show setup page with error
    return;
  }
  
  // Save credentials
  preferences.putString("wifi_ssid", ssid);
  preferences.putString("wifi_password", password);
  Serial.print("💾 Saved WiFi credentials: ");
  Serial.println(ssid);
  
  // Update saved credentials and trigger connection
  savedSSID = ssid;
  savedPassword = password;
  
  // Show connection page
  String html = "<!DOCTYPE html><html><head><title>Connecting...</title>";
  html += "<meta http-equiv='refresh' content='10;url=/'>";
  html += "<style>body{font-family:Arial,sans-serif;text-align:center;margin:50px auto;max-width:400px;}";
  html += ".connecting{background:#cce5ff;color:#004085;padding:20px;border-radius:8px;margin:20px 0;}";
  html += "</style></head><body>";
  html += "<h1>Connecting...</h1>";
  html += "<div class='connecting'>";
  html += "<p>Tabbie is connecting to " + ssid + "</p>";
  html += "<p>This page will redirect in 10 seconds.</p>";
  html += "<p>If connection fails, you'll see the setup page again.</p>";
  html += "</div>";
  html += "</body></html>";
  
  server.send(200, "text/html", html);
  
  // Reset WiFi state to trigger fresh connection
  Serial.println("🔄 Restarting WiFi connection...");
  prepareWiFiForRetry(500);
  isInSetupMode = false;
  wifiStatus = "connecting";
  wifiAttemptCount = 0;
  
  Serial.println("📡 WiFi will connect in background...");
}

void handleWiFiSettings() {
  if (isInSetupMode) {
    handleSetupPage();
    return;
  }
  
  String html = "<!DOCTYPE html><html><head><title>Tabbie WiFi Settings</title>";
  html += "<style>body{font-family:Arial,sans-serif;max-width:600px;margin:50px auto;padding:20px;}";
  html += "button{background:#007bff;color:white;padding:10px 20px;border:none;border-radius:5px;margin:5px;cursor:pointer;}";
  html += "button.danger{background:#dc3545;}button:hover{opacity:0.9;}</style></head><body>";
  html += "<h1>Tabbie WiFi Settings</h1>";
  html += "<p><strong>Current Network:</strong> " + WiFi.SSID() + "</p>";
  html += "<p><strong>IP Address:</strong> " + WiFi.localIP().toString() + "</p>";
  html += "<p><strong>Signal Strength:</strong> " + String(WiFi.RSSI()) + " dBm</p>";
  html += "<h3>Actions:</h3>";
  html += "<button onclick=\"if(confirm('Reconfigure WiFi? Tabbie will restart in setup mode.'))window.location='/wifi?action=reset'\">Change WiFi Network</button>";
  html += "<button onclick=\"window.location='/'\">Back to Dashboard</button>";
  html += "</body></html>";
  
  if (server.arg("action") == "reset") {
    // Clear saved credentials and restart in setup mode
    preferences.remove("wifi_ssid");
    preferences.remove("wifi_password");
    
    html = "<!DOCTYPE html><html><head><title>WiFi Reset</title>";
    html += "<meta http-equiv='refresh' content='3;url=/'>";
    html += "</head><body style='font-family:Arial,sans-serif;text-align:center;margin:50px;'>";
    html += "<h1>WiFi Settings Reset</h1>";
    html += "<p>Tabbie is restarting in setup mode...</p>";
    html += "<p>Connect to \"Tabbie-Setup\" to reconfigure.</p></body></html>";
    
    server.send(200, "text/html", html);
    delay(1000);
    ESP.restart();
  }
  
  server.send(200, "text/html", html);
}

void handleStatus() {
  server.sendHeader("Access-Control-Allow-Origin", "*");
  server.sendHeader("Content-Type", "application/json");
  
  JsonDocument doc;
  doc["status"] = wifiStatus;
  doc["animation"] = currentAnimation;
  doc["task"] = currentTask;
  doc["uptime"] = millis();
  doc["setupMode"] = isInSetupMode;
  
  if (!isInSetupMode && WiFi.status() == WL_CONNECTED) {
    doc["ip"] = WiFi.localIP().toString();
    doc["ssid"] = WiFi.SSID();
    doc["rssi"] = WiFi.RSSI();
  } else if (isInSetupMode) {
    doc["ip"] = WiFi.softAPIP().toString();
    doc["connectedDevices"] = WiFi.softAPgetStationNum();
  }
  
  String response;
  serializeJson(doc, response);
  server.send(200, "application/json", response);
}

void handleReset() {
  server.sendHeader("Access-Control-Allow-Origin", "*");
  server.sendHeader("Content-Type", "application/json");
  
  Serial.println("🔄 Resetting WiFi credentials...");
  
  // Clear saved WiFi credentials
  preferences.remove("wifi_ssid");
  preferences.remove("wifi_password");
  
  server.send(200, "application/json", "{\"success\":true,\"message\":\"WiFi credentials cleared. Restarting in setup mode...\"}");
  
  delay(1000);
  ESP.restart();
}

void handleDebug() {
  server.sendHeader("Access-Control-Allow-Origin", "*");
  server.sendHeader("Content-Type", "application/json");
  
  // Activate debug mode - shows device info on OLED for 8 seconds
  isDebugMode = true;
  debugModeStartTime = millis();
  
  Serial.println("🔧 Debug mode activated - showing device info on OLED");
  
  JsonDocument response;
  response["success"] = true;
  response["message"] = "Debug info displayed on OLED for 8 seconds";
  response["ip"] = WiFi.localIP().toString();
  response["ssid"] = WiFi.SSID();
  response["rssi"] = WiFi.RSSI();
  response["uptime"] = millis();
  response["animation"] = currentAnimation;
  response["wifiStatus"] = wifiStatus;
  response["mac"] = WiFi.macAddress();
  
  String responseStr;
  serializeJson(response, responseStr);
  server.send(200, "application/json", responseStr);
}
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

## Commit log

2025-05-02 2. Potentiometer
    [circle 2 cm with hole 0.22 cm.stl]
2025-05-07 updated head for servo
    [tabbie-head.stl]
2025-05-08 started esp-32
    [tabbie-head-prusa-file.3mf, tabbie-head.stl]
2025-05-09 updated 3d files
    [tabbie-head-prusa-file.3mf, tabbie-neck.stl]
2025-05-15 Some progress for ESP32
2025-05-16 learning esp32-3
2025-05-18 trying esp32
2025-05-21 esp32 button press turn on led
2025-05-21 updated folder structure
    [circle 2 cm with hole 0.22 cm.stl, tabbie-head.stl, tabbie-neck.stl]
2025-05-25 turn on led with button press & base verison of website
2025-05-28 react dashboard now connects the most common esp32 ips
2025-06-08 init 03-esp-32-led-screen
2025-06-22 add fresh esp32 easily and connect to wifi.
2025-07-02 Add gamification hints: XP progress bar, Upgrade Tabbie section, and +XP indicators
    - Added XP progress bar (0%) in sidebar header with 'Coming Soon' label
    - Added new 'Rewards' section with disabled 'Upgrade Tabbie' and 'Achievements' buttons
    - Added subtle '+XP' indicator on completed tasks to hint at future reward system
    - All elements are clearly marked as coming soon to build anticipation
    - Non-functional placeholders ready for future XP system implementation
2025-07-02 Clean up gamification hints: consolidate into single Upgrade Tabbie section
    - Removed cluttered XP progress bar from header
    - Removed separate 'Achievements' tab (felt gimmicky)
    - Consolidated everything into one 'Upgrade Tabbie' button
    - Added embedded mini progress bar with '0 XP' indicator
    - Much cleaner, less overwhelming design
    - Still hints at future XP/upgrade system without being pushy
2025-07-02 Create beautiful gamification preview card with better UX
    - Replaced simple button with engaging gradient card design
    - Added visual hierarchy with proper spacing and typography
    - Beautiful blue-to-purple gradient background with hover effects
    - Detailed XP progress bar showing '0 / 100 XP' with gradient fill
    - Preview of specific features: animations, head designs, badges
    - Floating 'Soon' badge and gradient trophy icon
    - Interactive hover effects that feel alive but clearly indicate coming soon
    - Much more engaging and builds real anticipation for XP system
    - Professional card design that fits well in sidebar
2025-07-02 Show overdue duration in tooltips for better urgency awareness
    - Changed from 'Overdue since Dec 20' to 'Overdue for 3 days'
    - Smart scaling: days → weeks → months
    - Examples: 'Overdue for 1 day', 'Overdue for 2 weeks', 'Overdue for 1 month'
    - Much more actionable than just showing the date
    - Immediate understanding of urgency level
    - Better decision making about task prioritization
2025-07-02 Add GitHub-style productivity dashboard with Tabbie Life section
    - Created comprehensive DashboardPage with activity visualization
    - Added GitHub-style contribution graph for tasks and pomodoros
    - Included productivity stats (today, week, month, year)
    - Interactive tooltips showing daily activity details
    - Quick action buttons for task creation and pomodoro
    - Added 'Tabbie Life' section at bottom for ESP32 hardware control
    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
2025-07-26 esp32 face update
2025-07-28 pomodoro working with esp32 screen thing
2025-09-01 need a new screen, mine burnt
    [main.cpp]
2025-09-05 new folder structure
    [circle 2 cm with hole 0.22 cm.stl, tabbie-head.stl, tabbie-neck.stl]
2025-09-18 trying with the ap mode esp32 (no wifi) works but no wifi
2025-10-03 added STL files
    [Antenna1.stl, Antenna2.stl, Bottom_case_cover.stl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]
2025-10-19 updated print files
    [Antenna1.stl, Antenna2.stl, Bottom_case_cover.stl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]
2025-10-20 final stl files I think
    [antenna.stl]
2025-10-20 actually final files
    [antenna2.stl, neck.stl]
2025-10-22 feat: implement 5-second completion animation for task finishing
    - Add isPlayingCompletionAnimation lock to prevent sync interruption
    - Update triggerTaskCompletion to play complete animation for exactly 5 seconds
    - Protect automatic sync logic from overriding completion animation
    - Ensures smooth transition from complete -> idle after task completion
2025-10-28 upading get started
    Updated wiring instructions and restructured steps for clarity.
2025-10-29 updated stl file
2025-10-29 added new face animations (just images for now) & fixed some bugs
    [main.cpp]
2025-10-29 Correct file paths in get_started.md
    Updated file paths for STL and GCODE files to include the 'hardware' directory.
2025-10-31 added new face animations + startup fix
    [main.cpp]
2025-10-31 Add Animation Streaming Component and Enhance WiFi Connection Logic
    - Integrated AnimationStreamingTest component into TabbiePage for improved UI experience.
    - Refactored WiFi connection handling in main.cpp to support retries and better state management.
    - Introduced functions for loading WiFi credentials, handling connection failures, and preparing for retries.
    - Updated setup and normal modes to ensure proper WiFi initialization and state cleanup.
    - Enhanced display updates to reflect connection status and animations during WiFi connection attempts.
    [main.cpp]
